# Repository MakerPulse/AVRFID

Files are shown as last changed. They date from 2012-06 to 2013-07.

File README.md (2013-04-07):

RPI-RFID
========

This project is ment to be used to scan and process RFID tags for attendance lists or access control.

Source - The code that is loaded onto the actual ID reader
Python_Interface - The GUI interface that is used to manage the attendance system
Circuit - The schematic and layout designes of the circuit board used to read the RFID tags
CaseCad - The CAD files for 3D printing the case for the circuit board

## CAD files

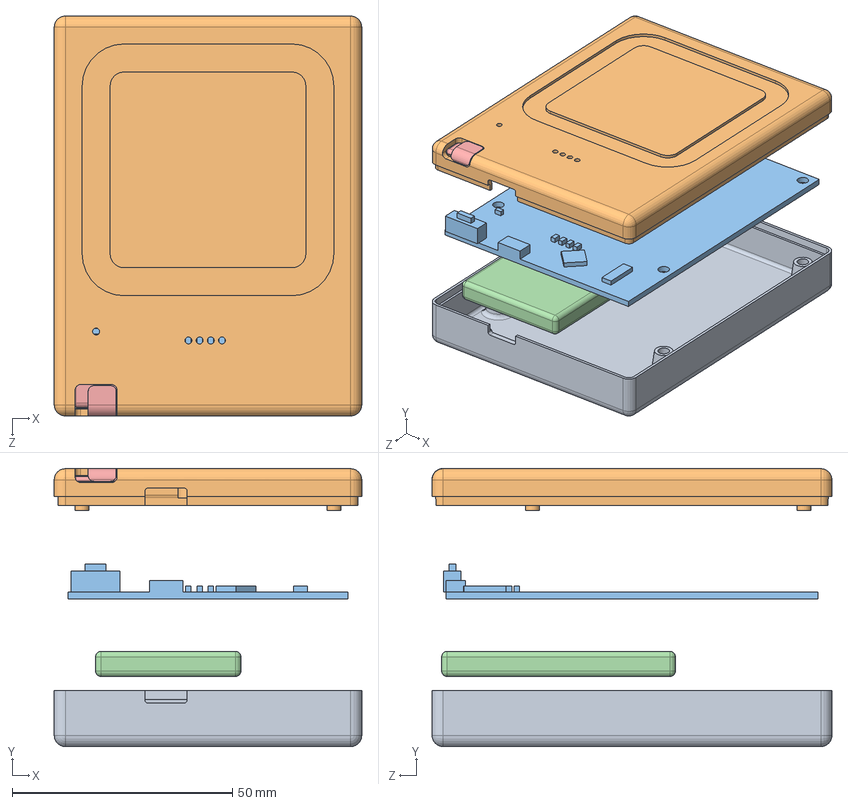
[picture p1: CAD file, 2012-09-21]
CaseCad/Assem1.SLDASM
69.8 x 63.2 x 90.8 mm
side1
side2
PCB
battery
switch

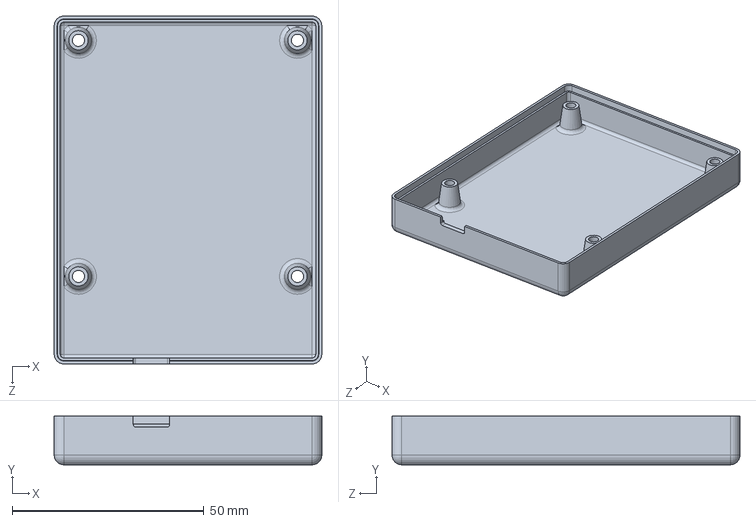
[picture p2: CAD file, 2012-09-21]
CaseCad/side1.SLDPRT
69.8 x 12.7 x 90.8 mm

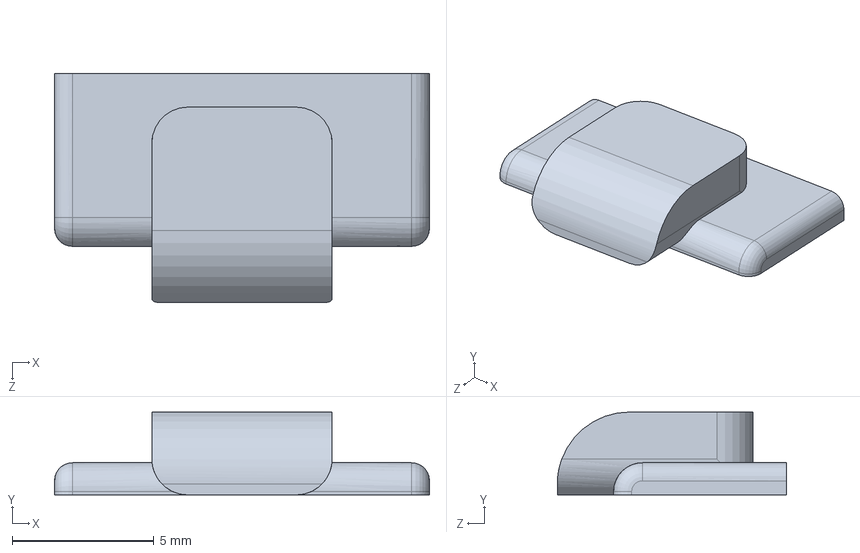
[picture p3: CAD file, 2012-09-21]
CaseCad/switch.SLDPRT
13.2 x 2.92 x 8.08 mm

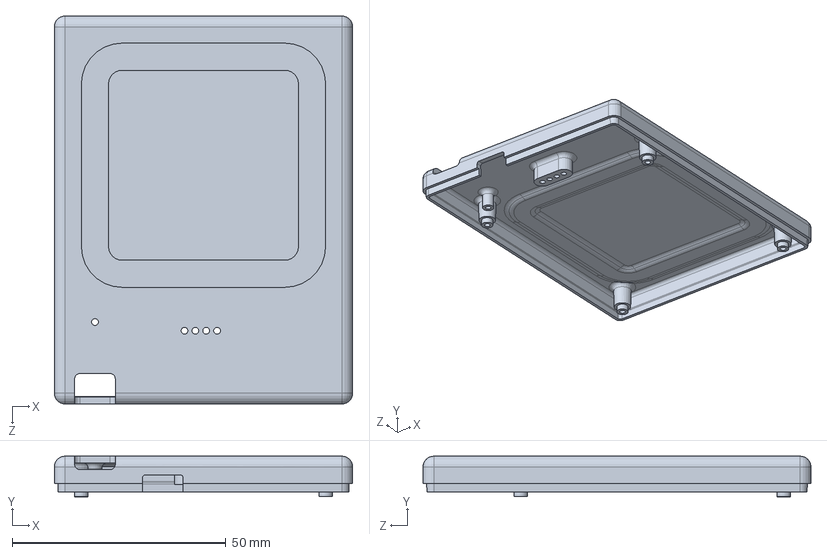
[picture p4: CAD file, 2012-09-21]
CaseCad/side2.SLDPRT
69.8 x 9.54 x 90.8 mm

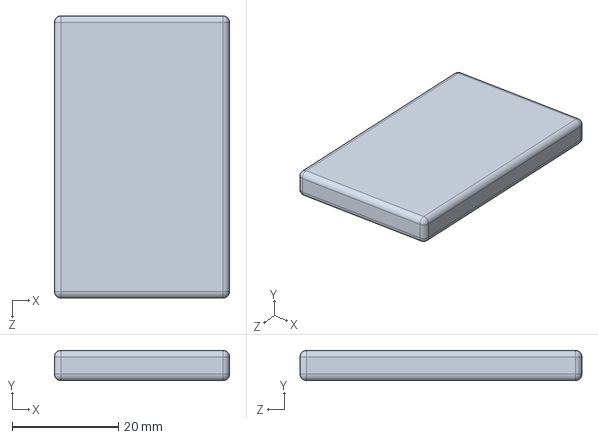
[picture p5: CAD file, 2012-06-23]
CaseCad/battery.SLDPRT
33.0 x 5.72 x 53.1 mm

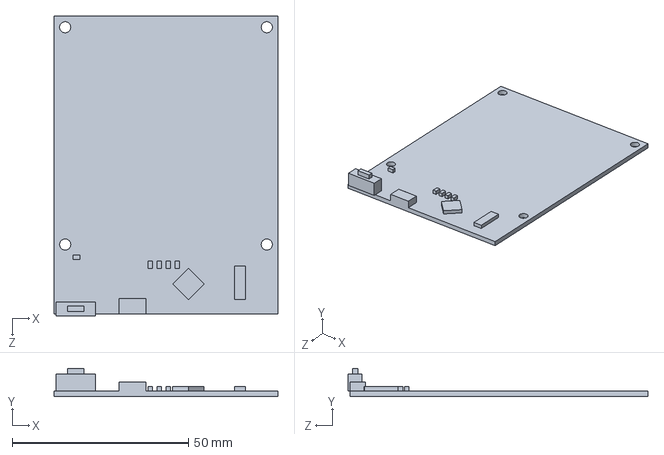
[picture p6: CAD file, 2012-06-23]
CaseCad/PCB.SLDPRT
63.5 x 7.95 x 85.0 mm

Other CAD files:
CaseCad/side1.STL
CaseCad/side2.STL
CaseCad/switch.STL

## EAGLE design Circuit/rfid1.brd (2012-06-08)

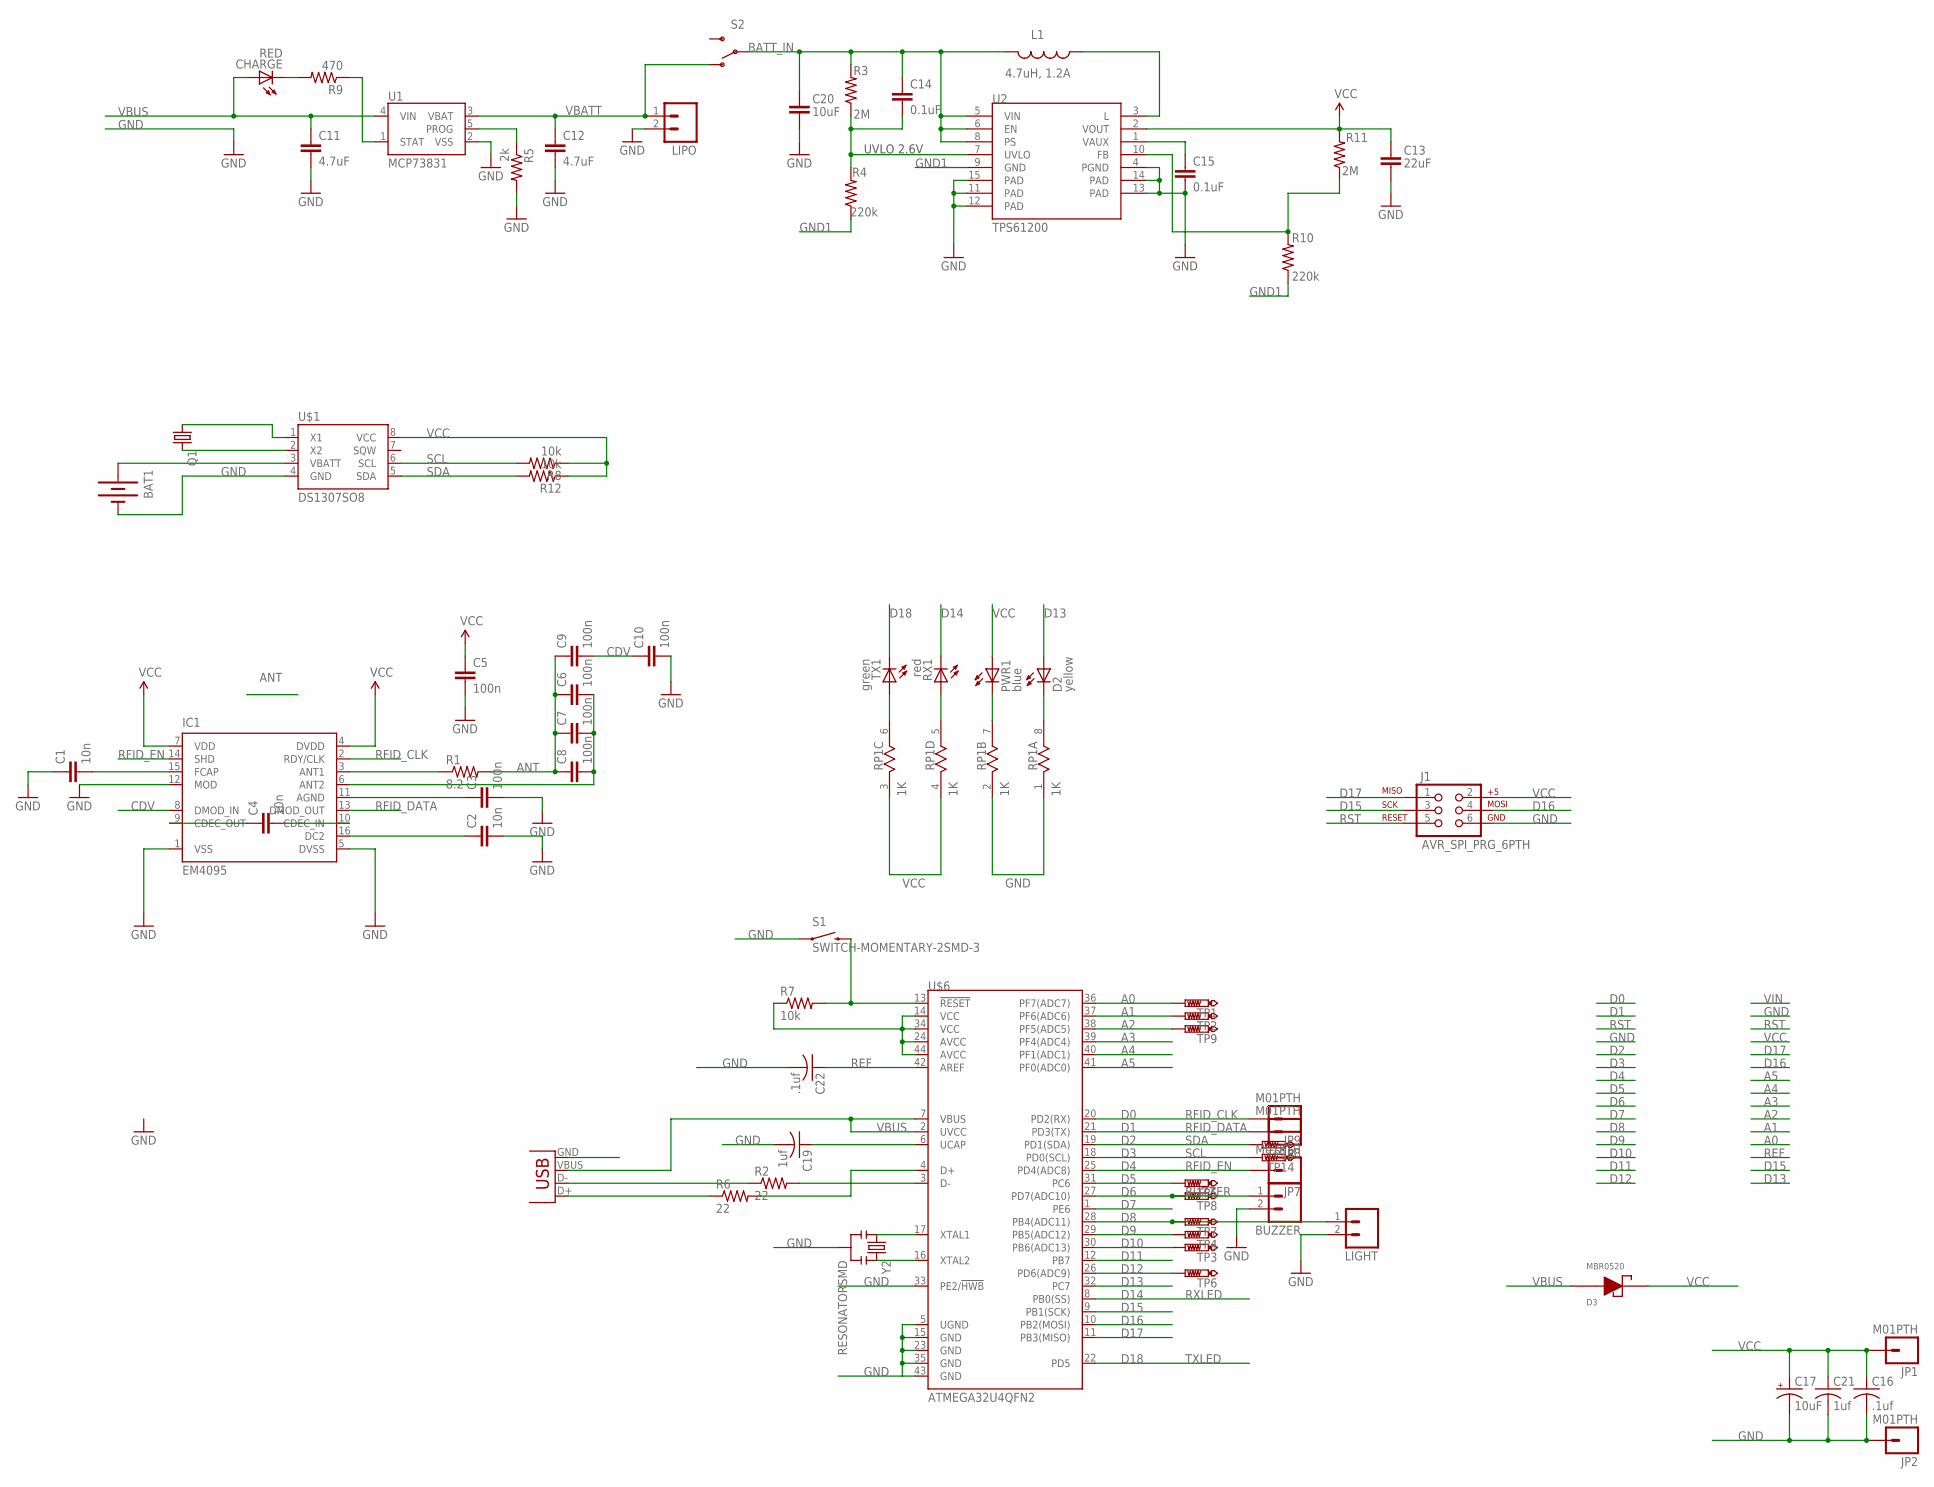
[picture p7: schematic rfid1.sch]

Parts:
BAT1: BATTERY12MM; BATTCON_12MM
BUZZER: M02PTH; 1X02
C1, C2, C4: 10n; 0805
C3, C5, C6, C7, C8, C9, C10: 100n; 0805
C11, C12: 4.7uF; 0603-CAP
C13: 22uF; 0805
C14, C15: 0.1uF; 0603-CAP
C16, C22: .1uf; C0603
C17: 10uF; EIA3216
C19, C21: 1uf; C0603
C20: 10uF; 1206
CHARGE: RED; CHIPLED_0805
D2: yellow; CHIPLED_0805
D3: MBR0520; SOD-123
IC1: EM4095; SO16
J1: AVR_SPI_PRG_6PTH; 2X3
JP1, JP2, JP7, JP8, JP9: M01PTH; 1X01
L1: 4.7uH, 1.2A; CDRH2D09
LIGHT: M02PTH; 1X02
LIPO: M02-JST-2-PTH-NO_SILK; JST-2-PTH-NS
PWR1: blue; CHIPLED_0805
Q1: CRYSTALTC26H; TC26H
R1: 8.2; 0805
R2, R6: 22; 0603-RES
R3, R11: 2M; 0603-RES
R4, R10: 220k; 0603-RES
R5: 2k; 0603-RES
R7, R8, R12: 10k; 0603-RES
R9: 470; 0603-RES
RP1: 1K; RES4NT
RX1: red; CHIPLED_0805
S1: SWITCH-MOMENTARY-2SMD-3; TACTILE_SWITCH_SMD-3
S2: SWITCH-SPDTPTH; SWITCH-SPDT
TP1, TP2, TP3, TP4, TP5, TP6, TP7, TP8, TP9, TP13, TP14: PTR1TP14R; TP14R
TX1: green; CHIPLED_0805
U1: MCP73831; SOT23-5
U2: TPS61200; QFN-10_PAD
U$1: DS1307SO8; SO08
U$6: ATMEGA32U4QFN2; QFN-44-NOPAD
X2: USB-MICROB
Y2: RESONATORSMD; RESONATOR-SMD

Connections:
A0: TP1.TP, U$6.36 (PF7(ADC7))
A1: TP2.TP, U$6.37 (PF6(ADC6))
A2: TP9.TP, U$6.38 (PF5(ADC5))
A3: U$6.39 (PF4(ADC4))
A4: U$6.40 (PF1(ADC1))
A5: U$6.41 (PF0(ADC0))
ANT: C6.1, C7.1, C8.1, C9.1, R1.2
BATT_IN: C14.1, C20.1, L1.P$2 (2), R3.2, S2.2, U2.5 (VIN), U2.6 (EN), U2.8 (PS)
CDV: C9.2, C10.1, IC1.8 (DMOD_IN)
D5: TP5.TP, U$6.31 (PC6)
D6: BUZZER.1, TP8.TP, U$6.27 (PD7(ADC10))
D7: U$6.1 (PE6)
D8: LIGHT.1, TP7.TP, U$6.28 (PB4(ADC11))
D9: TP4.TP, U$6.29 (PB5(ADC12))
D10: TP3.TP, U$6.30 (PB6(ADC13))
D11: U$6.12 (PB7)
D12: TP6.TP, U$6.26 (PD6(ADC9))
D13: D2.A, U$6.32 (PC7)
D14: RX1.C, U$6.8 (PB0(SS))
D15: J1.3, U$6.9 (PB1(SCK))
D16: J1.4, U$6.10 (PB2(MOSI))
D17: J1.1, U$6.11 (PB3(MISO))
D18: TX1.C, U$6.22 (PD5)
FB: R10.2, R11.1, U2.10 (FB)
GND: BAT1.GND (-), BUZZER.2, C1.1, C2.2, C3.2, C5.2, C10.2, C11.2, C12.2, C13.2, C15.2, C16.2, C17.C (-), C19.2, C20.2, C21.2, C22.2, IC1.1 (VSS), IC1.5 (DVSS), IC1.12 (MOD), J1.6, JP2.1, LIGHT.2, LIPO.2, R5.2, RP1.1, RP1.2 (1), S1.P$1 (1), U1.2 (VSS), U2.4 (PGND), U2.11 (PAD), U2.12 (PAD), U2.13 (PAD), U2.14 (PAD), U2.15 (PAD), U$1.4 (GND), U$6.5 (UGND), U$6.15 (GND), U$6.23 (GND), U$6.33 (PE2/!HWB), U$6.35 (GND), U$6.43 (GND), X2.GND, Y2.2
GND1: R4.1, R10.1, U2.9 (GND)
unnamed: IC1.3 (ANT1), R1.1
unnamed: CHARGE.C, R9.2
unnamed: U$6.16 (XTAL2), Y2.3
unnamed: C6.2, C7.2, C8.2, IC1.6 (ANT2)
unnamed: L1.P$1 (1), U2.3 (L)
unnamed: C3.1, IC1.11 (AGND)
unnamed: C4.2, IC1.10 (CDEC_IN)
unnamed: C4.1, IC1.9 (CDEC_OUT)
unnamed: C15.1, U2.1 (VAUX)
unnamed: R5.1, U1.5 (PROG)
unnamed: C2.1, IC1.16 (DC2)
unnamed: R9.1, U1.1 (STAT)
unnamed: C1.2, IC1.15 (FCAP)
unnamed: Q1.1, U$1.1 (X1)
unnamed: U$6.17 (XTAL1), Y2.1
unnamed: Q1.2, U$1.2 (X2)
unnamed: BAT1.PWR@1 (+), U$1.3 (VBATT)
unnamed: R6.2, U$6.4 (D+)
unnamed: R2.2, U$6.3 (D-)
unnamed: C19.1, U$6.6 (UCAP)
unnamed: R2.1, X2.D-
unnamed: R6.1, X2.D+
unnamed: RP1.6 (2), TX1.A
unnamed: RP1.5 (2), RX1.A
unnamed: PWR1.C, RP1.7 (2)
unnamed: D2.C, RP1.8 (2)
REF: C22.1, U$6.42 (AREF)
RFID_CLK: IC1.2 (RDY/CLK), JP9.1, U$6.20 (PD2(RX))
RFID_DATA: IC1.13 (DMOD_OUT), JP8.1, U$6.21 (PD3(TX))
RFID_EN: IC1.14 (SHD), JP7.1, U$6.25 (PD4(ADC8))
RST: J1.5, R7.2, S1.P$2 (2), U$6.13 (!RESET)
SCL: R8.2, TP14.TP, U$1.6 (SCL), U$6.18 (PD0(SCL))
SDA: R12.2, TP13.TP, U$1.5 (SDA), U$6.19 (PD1(SDA))
UVLO: C14.2, R3.1, R4.2, U2.7 (UVLO)
VBATT: C12.1, LIPO.1, S2.1 (O), U1.3 (VBAT)
VBUS: C11.1, CHARGE.A, D3.2 (AN), U1.4 (VIN), U$6.2 (UVCC), U$6.7 (VBUS), X2.VBUS
VCC: C5.1, C13.1, C16.1, C17.A (+), C21.1, D3.1 (CA), IC1.4 (DVDD), IC1.7 (VDD), J1.2, JP1.1, PWR1.A, R7.1, R8.1, R11.2, R12.1, RP1.3 (1), RP1.4 (1), U2.2 (VOUT), U$1.8 (VCC), U$6.14 (VCC), U$6.24 (AVCC), U$6.34 (VCC), U$6.44 (AVCC)

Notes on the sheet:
RXLED
TXLED
UVLO 2.6V
BUZZER

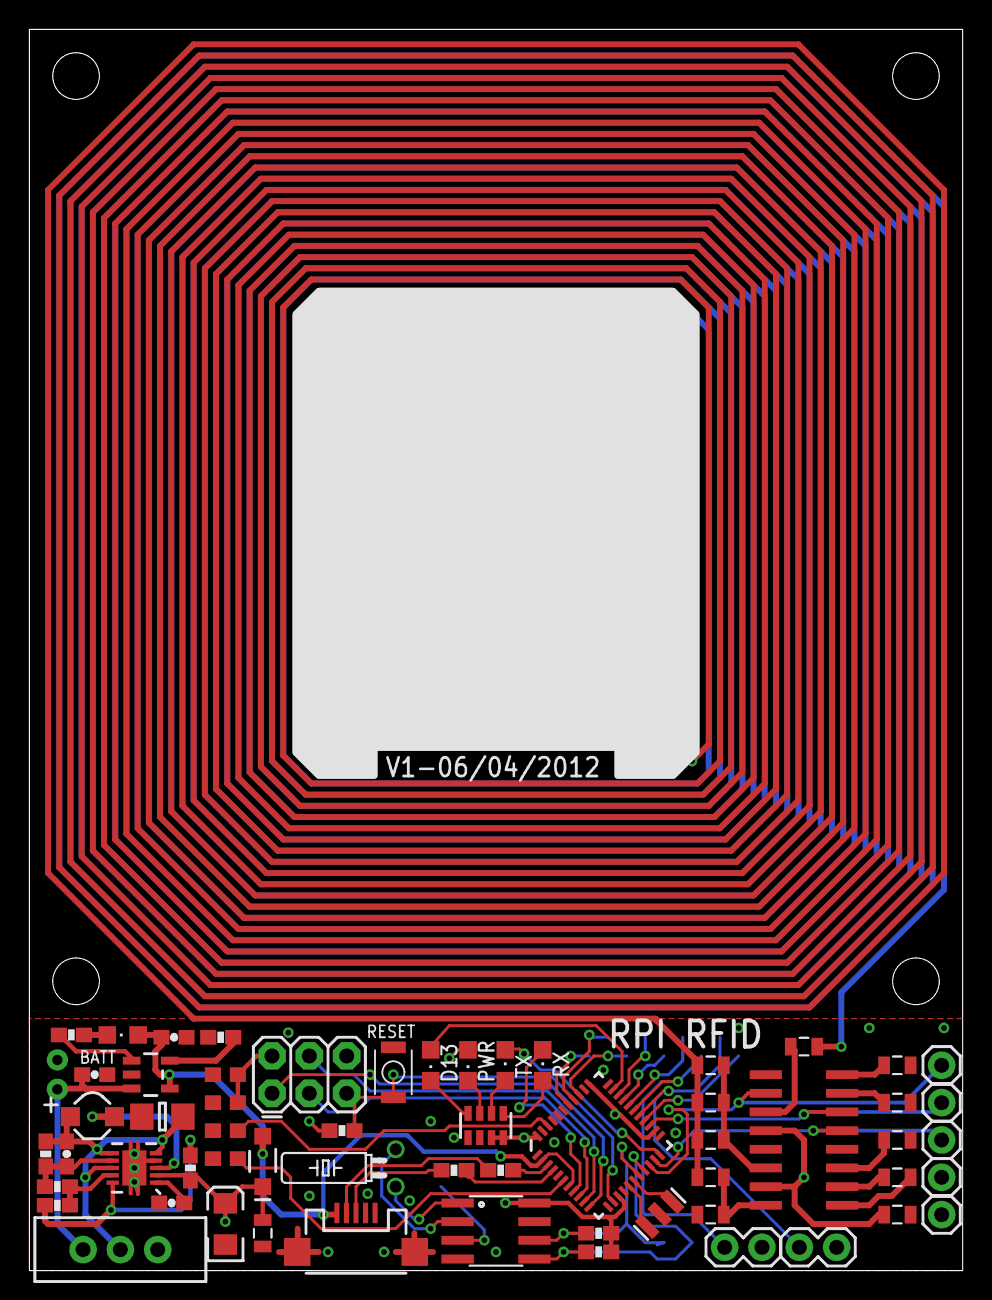
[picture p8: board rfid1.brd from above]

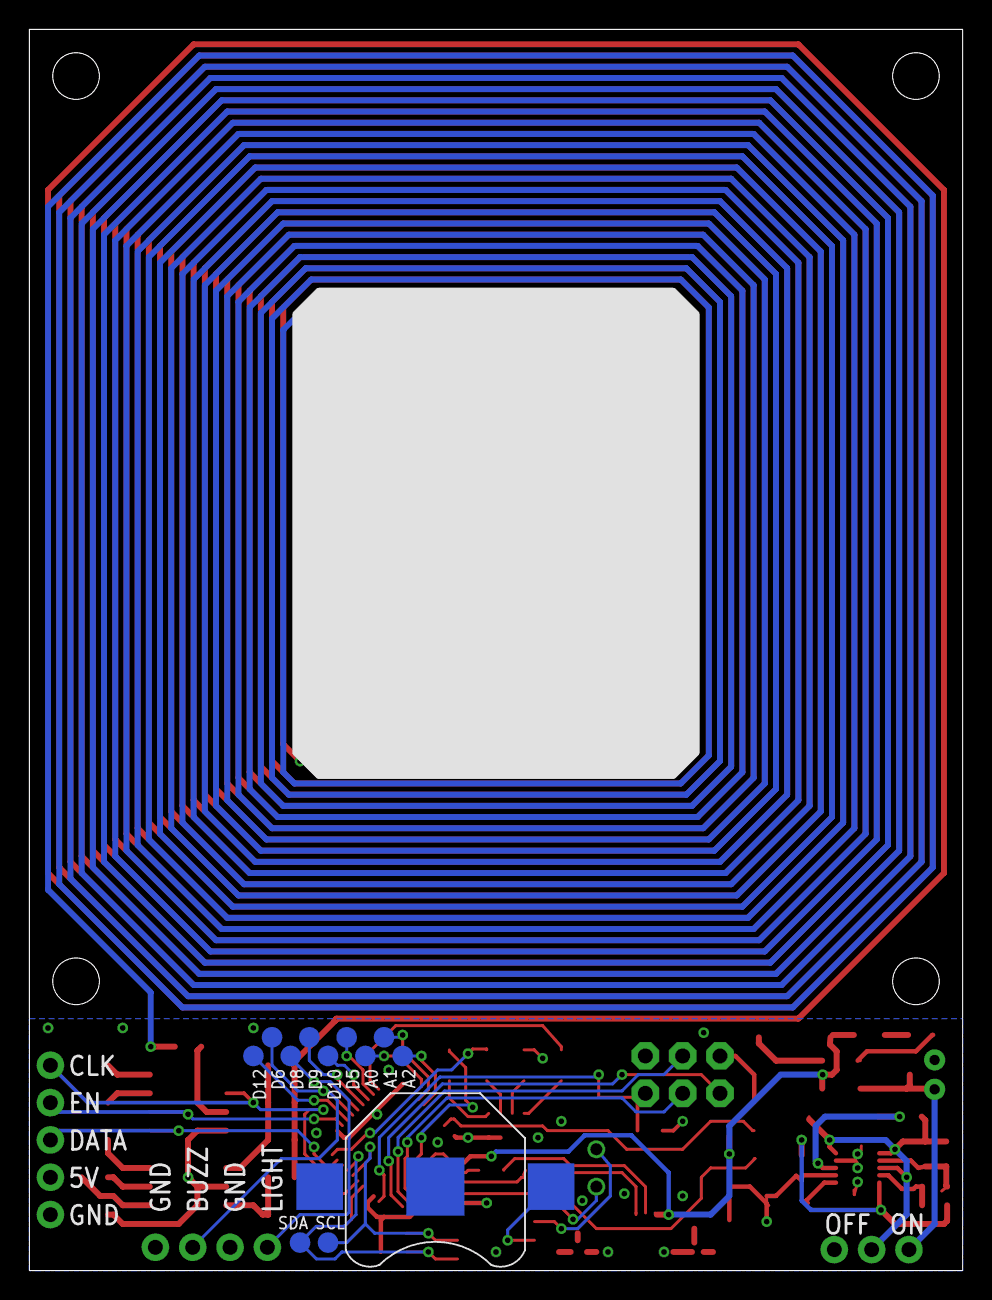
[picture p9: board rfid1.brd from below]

Board: 2 copper layers, 63.5 x 84.5 mm, 72 parts (13 on the bottom side), 58 nets.

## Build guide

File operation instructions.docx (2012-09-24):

Using RPI RFID Read software

Open the application RFID_Serial_Interface3.exe. Note the date displayed in the upper left corner. This is the name that will be assigned to the output file. The numbers in the lower left corner represent the mouse coordinates. These can be ignored.

click load, and navigate to RFID list file. This is a .csv (comma separated value) file containing a list of names, RCS IDs, RFID tags, and roles. The roles category is user configurable, and for reference only. It has no effect on the operation of the program, so long as it doesn’t exceed 30 characters. The header is defined in the CSV file.

Click open. The program will load the names into the list. Note the open file name in the upper right corner.

In order to begin scanning IDs, we need to open the serial port the RFID reader is connected to. Use device manager to identify the correct COM Port. I know that COM 10 is the RFID reader on my system, but it will be different from system to system. Usually it is a lower number.

Click the ‘serial’ button to detect and select the serial port. It will take a few seconds to load. Enter the number preceding the correct port. This example is 2. Press enter.

The port will open and the program will display ‘OK to scan’ indicating that it is ready to scan IDs and log entries. It will also show the open port next to the file name. The system is ready to scan IDs now.

Scanning an ID causes the list to jump to the correct ID location in the list, and mark that person as ‘present’.

If an ID is scanned that is not in the list, it will prompt the user to enter the rest of the information, then add the new entry to the list and mark as present.

Clicking edit allows the user to change the information of the current entry. The information must be entered in the format specified, and include the name, email, and user field with no spaces between commas. Sorry. It also allows the user to scan a new or replacement ID.

Clicking ‘add’ allows the user to add a new entry by name. The field must be entered as described, without spaces between the commas. Sorry. It assigns an ID of ‘00000000000’ and marks them as present. This is generally only used for RPI Faculty, staff, or students who forget their ID, or for attendees without an RPI ID.

Attendees can be marked as present manually using the ‘mark’ button. This toggles the ‘present’ state.

A user can search the list for a matching string in any of the Name, email, or role fields. The text is case sensitive and must match exactly, including spaces. First or Last name only are not enough, it must be the exact entered name. Short or nicknames in the list may cause problems here. Entering the email correctly is the best option for reliable searches each time. Scanning an ID will cause the list to jump to a correct entry if available.

If an attendee is known to be on the list, but their ID says they are unknown, they may have gotten a new ID. Click ‘search’ to search for their email before adding a new entry. If that turns up nothing, create a new entry.

Closing the application will save both the list of names, emails, RFID tags, and roles, and the list of those present for the event. If another event is needed for the day, the file name must be manually changed on the first before saving the second, or it will be overwritten. The list file location is the same as it was selected. The event file location is in the same folder from which the application was run.

Known Issues

- Event files are overwritten, and cannot be appended to. This means one event per day without closing the application between reads, or without manually changing the file name
- Event file location is not configurable within the application. It can be changed in source though.

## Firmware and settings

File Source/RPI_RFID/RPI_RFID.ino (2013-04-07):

/******************************* CUSTOM SETTINGS ******************************\
| Settings that can be changed, comment or uncomment these #define settings to |
| make the AVRFID code do different things
\******************************************************************************/

//#define Binary_Tag_Output         // Outputs the Read tag in binary over serial
#define Hexadecimal_Tag_Output    // Outputs the read tag in Hexadecimal over serial
//#define Decimal_Tag_Output        // Outputs the read tag in decimal

#define Manufacturer_ID_Output    // The output will contain the Manufacturer ID (NOT IMPLEMENTED)
#define Site_Code_Output          // The output will contain the Site Code       (NOT IMPLEMENTED)
#define Unique_Id_Output          // The output will contain the Unique ID

//#define Split_Tags_With '-'       // The character to split tags pieces with


//20-bit manufacturer code,
#define MANUFACTURER_ID_OFFSET 0
#define MANUFACTURER_ID_LENGTH 20

//8-bit site code
#define SITE_CODE_OFFSET 20
#define SITE_CODE_LENGTH 8

//16-bit unique id
#define UNIQUE_ID_OFFSET 28
#define UNIQUE_ID_LENGTH 16



// these settings are used internally by the program to optimize the settings above
#ifndef serialOut
  #define serialOut
#endif


/// countBuffer the includes

//#include <avr/io.h>
//#include <avr/interrupt.h>
//#include <stdlib.h>

#define ARRAYSIZE 900   // Number of RF points to collect each time
#define bufferType char

bufferType * countBuffer;           // points to the bigining of the array
int * names;            // array of valid ID numbers
int namesize;           // size of array of valid ID numbers
volatile int iter;      // the iterator for the placement of count in the array
volatile int count;     // counts 125kHz pulses
volatile int lastpulse; // last value of DEMOD_OUT
volatile int on;        // stores the value of DEMOD_OUT in the interrupt


/******************************* MAIN FUNCTION *******************************\
| This is the main function, it initilized the variabls and then waits for    |
| interrupt to fill the buffer before analizing the gathered data             |
\*****************************************************************************/
void setup () {
  
  ///////////// PIN INITILIZATION /////////////
  //DDRD = 0x00; // 00000000 configure output on port D
  //DDRB = 0x1E; // 00011100 configure output on port B
  
  // USART INITILIZATION
  Serial.begin(9600);
  Serial.println("Finished setup");
  //Serial.end();
  //Serial1.countBuffer(9600);
  //Serial1.println("Serial  1");
  //Serial2.countBuffer(9600);
  //Serial2.println("Serial 2");
  
  /////////// VARIABLE INITILIZATION //////////
  count = 0;
  countBuffer = (bufferType *) malloc (sizeof(bufferType)*ARRAYSIZE);
  iter = 0;
  for (int i = 0; i < ARRAYSIZE; i ++) {
    countBuffer[i] = 0;
  }
  
  ////////// INTERRUPT INITILAIZATION /////////
  //sei ();       // enable global interrupts
  //cli ();// disable global interrupts
  //__enable_interrupt();
  EIMSK = 0x00;
  EICRA = 0x30; // configure interupt INT2 B 0011 0000
  //enableAntenna();
  //__disable_interrupt();
  sei();
  Serial.println("Finished setup");
  pinMode(4,OUTPUT);
  digitalWrite(4,LOW);
  //pinMode(1,INPUT);
  //DDRD &= 0xFC;
  DDRD &= ~0x04;
  DDRD &= ~0x02;
  //PORTD |= 0x06;
  
  DDRD |= 0x80;
  PORTD |= 0x80;
  
  pinMode(13,OUTPUT);
  digitalWrite(13,HIGH);
}

void loop () {
  Serial.end();
  enableAntenna();
  //__enable_interrupt();  
  while (1) { // while the card is being read
    /*Serial.print(on);
    Serial.print(" ");
    Serial.println(count);*/
    if (iter >= ARRAYSIZE) { // if the buffer is full
      disableAntenna();
      //__disable_interrupt();
      //noInterrupts();
      break; // continue to analize the buffer
    }
  }  
  //Serial.println("Finished array");
  //PORTB &= ~0x1C;
  Serial.begin(9600);
  //analize the array of input
  analizeInput ();
  
  //reset the saved values to prevent errors when reading another card
  count = 0;
  iter = 0;
  for (int i = 0; i < ARRAYSIZE; i ++) {
    countBuffer[i] = 0;
  }
}

/******************************* INT0 INTERRUPT *******************************\
| This ISR(INT0_vect) is the interrupt function for INT0. This function is the |
| function that is run each time the 125kHz pulse goes HIGH.                   |
| 1) If this pulse is in a new wave then put the count of the last wave into   |
|     the array                                                                |
| 2) Add one to the count (count stores the number of 125kHz pulses in each    |
|     wave                                                                     |
\******************************************************************************/
ISR(INT2_vect) {
  //Save the value of DEMOD_OUT to prevent re-reading on the same group
  on =(PIND & 0x08);
  
  //if (on==0x08) PORTD |= 0x80;
  //else { PORTD &= ~0x80; }
  
  //on = digitalRead(1);
  // if wave is rising (end of the last wave)
  if (on == 0x08 && lastpulse == 0 ) {
    //PORTD |= 0x80;
    // write the data to the array and reset the count
    countBuffer[iter] = count; 
    count = 0;
    iter = iter + 1;
  }
  count = count + 1;
  lastpulse = on;
}


void disableAntenna(){
  EIMSK = 0x00; // disable interrupt INT2    B 0000 0000
}
void enableAntenna() {
  EIMSK = 0x04; // enable interrupt INT2    B 0000 0100
}

  //////////////////////////////////////////////////////////////////////////////
 ////////////////////////// BASE CONVERSION FUNCTIONS /////////////////////////
//////////////////////////////////////////////////////////////////////////////
char binaryTohex (int four, int three, int two, int one) {
  int value = (one << 0) + (two << 1) + (three << 2) + (four << 3);
  if (value > 9) return 'A' + value - 10;
  return '0' + value;
}

/*********************** GET HEX ARRAY FROM BINARY ARRAY **********************\
|
\******************************************************************************/
int * getHexFromBinary (int * array, int length, int * result) {
  int i;
  int resultLength = (length+3)/4; // +3 so that the resulting number gets rounded up
  // 4 / 4 = 1       [correct]
  // 7 / 4 = 1 (4+3) [still correct]
  // 5 / 4 = 1       [not rounded up]
  // 8 / 4 = 2 (5+3) [correct]
  
  for (i = 0; i < resultLength; i++) {
    result[i*4] = (array[i+0] << 0)
                + (array[i+1] << 1)
                + (array[i+2] << 2)
                + (array[i+3] << 3);
  }
  return result;
}
/*************************** GET DECIMAL FROM BINARY **************************\
| This function will take in a binary input and return an intiger with the     |
| corrisponding value, assumed as decimal                                      |
\******************************************************************************/
int getDecimalFromBinary (int * array, int length) {  
  int result = 0;
  int i;
  for (i = 0; i < length; i++) {
    result = result<<1;
    result += array[i]&0x01;
  }
  return result;
}


void recurseDecimal (unsigned int val) {
  if (val > 0 ) {
    recurseDecimal(val/10);
    Serial.print(val%10);
  }
  return;
}

void printDecimal (int array[45]) {
  #ifdef Manufacturer_ID_Output
  int manufacturerId = getDecimalFromBinary( array + MANUFACTURER_ID_OFFSET,MANUFACTURER_ID_LENGTH);
  manufacturerId = getDecimalFromBinary( array + MANUFACTURER_ID_OFFSET,MANUFACTURER_ID_LENGTH);
  recurseDecimal(manufacturerId);
  #endif
  
  #ifdef Split_Tags_With
    Serial.print(Split_Tags_With);
  #endif
  
  #ifdef Site_Code_Output
  
  int siteCode = getDecimalFromBinary( array + SITE_CODE_OFFSET,SITE_CODE_LENGTH);
  recurseDecimal(siteCode);
  #endif

  #ifdef Split_Tags_With
    Serial.print(Split_Tags_With);
  #endif

  #ifdef Unique_Id_Output
  int lastId = getDecimalFromBinary( array + UNIQUE_ID_OFFSET,UNIQUE_ID_LENGTH);
  recurseDecimal(lastId);
  #endif
  
  Serial.print('\r');
  Serial.print('\n');
}
void printHexadecimal (int array[45]) {
  int i;
  #ifdef Manufacturer_ID_Output
  for (i = MANUFACTURER_ID_OFFSET; i < MANUFACTURER_ID_OFFSET+MANUFACTURER_ID_LENGTH; i+=4) {
    Serial.print(binaryTohex(array[i],array[i+1],array[i+2],array[i+3]));
  }
  #endif
  
  #ifdef Split_Tags_With
    Serial.print(Split_Tags_With);
  #endif
  
  #ifdef Site_Code_Output
  for (i = SITE_CODE_OFFSET; i < SITE_CODE_OFFSET+SITE_CODE_LENGTH; i+=4) {
    Serial.print(binaryTohex(array[i],array[i+1],array[i+2],array[i+3]));
  }
  #endif

  #ifdef Split_Tags_With
    Serial.print(Split_Tags_With);
  #endif

  #ifdef Unique_Id_Output
  for (i = UNIQUE_ID_OFFSET; i < UNIQUE_ID_OFFSET+UNIQUE_ID_LENGTH; i+=4) {
    Serial.print(binaryTohex(array[i],array[i+1],array[i+2],array[i+3]));
  }
  #endif
  Serial.print('\r');
  Serial.print('\n');
}



void printBinary (int array[45]) {
  int i;
  #ifdef Manufacturer_ID_Output
  for (i = MANUFACTURER_ID_OFFSET; i < MANUFACTURER_ID_OFFSET+MANUFACTURER_ID_LENGTH; i++) {
    Serial.print(array[i]);
  }
  #endif
  
  #ifdef Split_Tags_With
    Serial.print(Split_Tags_With);
  #endif
  
  #ifdef Site_Code_Output
  for (i = SITE_CODE_OFFSET; i < SITE_CODE_OFFSET+SITE_CODE_LENGTH; i++) {
    Serial.print(array[i]);
  }
  #endif

  #ifdef Split_Tags_With
    Serial.print(Split_Tags_With);
  #endif

  #ifdef Unique_Id_Output
  for (i = UNIQUE_ID_OFFSET; i < UNIQUE_ID_OFFSET+UNIQUE_ID_LENGTH; i++) {
    Serial.print(array[i]);
  }
  #endif
  Serial.print('\r');
  Serial.print('\n');
}



  //////////////////////////////////////////////////////////////////////////////
 ///////////////////////////// ANALYSIS FUNCTIONS /////////////////////////////
//////////////////////////////////////////////////////////////////////////////

/************************* CONVERT RAW DATA TO BINARY *************************\
| Converts the raw 'pulse per wave' count (5,6,or 7) to binary data (0, or 1)  |
\******************************************************************************/
void convertRawDataToBinary (bufferType * buffer) {
  int i;
  int outputOffset = 0;
  //Serial.print("FULL BUFFER");
  buffer[0] = -2;
  for (i = 1; i < ARRAYSIZE; i++) {
    /*
    if (buffer[i] == 5) {
      buffer[i] = 0;
    }
    else if (buffer[i] == 7) {
      buffer[i] = 1;
    }
    else if (buffer[i] == 6) {
       buffer[i] = buffer[i-1];
    }*/
    //Serial.print(int(buffer[i]));
    //Serial.print('|');
    
    if (buffer[i] <= 8 && buffer[i] >= 6) {
      buffer[i-outputOffset] = 0;
    }
    else if (buffer[i] >= 10 && buffer[i] <= 18) {
      buffer[i-outputOffset] = 1;
    }
    else if (buffer[i] == 9) {
      buffer[i-outputOffset] = buffer[i-outputOffset-1];
    }
    else {
      outputOffset++;//increase the offset so that this element gets overwritten by the next element instead
      buffer[ARRAYSIZE-outputOffset] = -2; // Set the end of the array to a -2 to prevent previous data from carrying over
    }
    
    //Serial.print(int(buffer[i-outputOffset]));
  }
  //Serial.println("");
}
/******************************* FIND START TAG *******************************\
| This function goes through the buffer and tries to find a group of fifteen   |
| or more 1's in a row. This sigifies the start tag. If you took the fifteen   |
| ones in multibit they would come out to be '111' in single-bit               |
\******************************************************************************/
int findStartTag (bufferType * buffer) {
  int i;
  int inARow = 0;
  int lastVal = 0;
  for (i = 0; i < ARRAYSIZE; i++) {
    if (buffer [i] == lastVal) {
      inARow++;
    }
    else {
      // End of the group of bits with the same value
      if (inARow >= 15 && lastVal == 1) {
        // Start tag found
        break;
      }
      // group of bits was not a start tag, search next tag
      inARow = 1;
      lastVal = buffer[i];
    }
  }
  return i;
}

/************************ PARSE MULTIBIT TO SINGLE BIT ************************\
| This function takes in the start tag and starts parsing the multi-bit code   |
| to produce the single bit result in the outputBuffer array the resulting     |
| code is single bit manchester code                                           |
\******************************************************************************/
void parseMultiBitToSingleBit (bufferType * buffer, int startOffset, int outputBuffer[]) {
  int i = startOffset; // the offset value of the start tag
  int lastVal = 0; // what was the value of the last bit
  int inARow = 0; // how many identical bits are in a row// this may need to be 1 but seems to work fine
  int resultArray_index = 0;
  for (;i < ARRAYSIZE; i++) {
    if (buffer [i] == lastVal) {
      inARow++;
    }
    else {
      // End of the group of bits with the same value
      if (inARow >= 4 && inARow <= 8) {
        // there are between 4 and 8 bits of the same value in a row
        // Add one bit to the resulting array
        outputBuffer[resultArray_index] = lastVal;
        resultArray_index += 1;
      }
      else if (inARow >= 9 && inARow <= 14) {
        // there are between 9 and 14 bits of the same value in a row
        // Add two bits to the resulting array
        outputBuffer[resultArray_index] = lastVal;
        outputBuffer[resultArray_index+1] = lastVal;
        resultArray_index += 2;
      }
      else if (inARow >= 15 && lastVal == 0) {
        // there are more then 15 identical bits in a row, and they are 0s
        // this is an end tag
        break;
      }
      // group of bits was not the end tag, continue parsing data
      inARow = 1;
      lastVal = buffer[i];
      if (resultArray_index >= 90) {
        //Serial.println("Out of bounds error");
        return;
      }
    }
  }
}

/******************************* Analize Input *******************************\
| analizeInput(void) parses through the global variable and gets the 45 bit   |
| id tag.                                                                     |
| 1) Converts raw pulse per wave count (5,6,7) to binary data (0,1)           |
| 2) Finds a start tag in the code                                            |
| 3) Parses the data from multibit code (11111000000000000111111111100000) to |
|     singlebit manchester code (100110) untill it finds an end tag           |
| 4) Converts manchester code (100110) to binary code (010)                   |
\*****************************************************************************/
void analizeInput (void) {
  //Serial.println ("READ ");
  
  int i;                // Generic for loop 'i' counter
  int resultArray[91];  // Parsed Bit code in manchester
  int finalArray[45];   //Parsed Bit Code out of manchester
  int finalArray_index = 0;
  
  // Initilize the arrays so that any errors or unchanged values show up as 2s
  for (i = 0; i < 90; i ++) { resultArray[i] = 2; }
  for (i = 0; i < 45; i++)  { finalArray[i] = 2;  }
  
  // Convert raw data to binary
  convertRawDataToBinary (countBuffer);
  
  
  
  
  
  // Find Start Tag
  int startOffset = findStartTag(countBuffer);
  //PORTB |= 0x10; // turn an led on on pin B5)
  
  // Parse multibit data to single bit data
  parseMultiBitToSingleBit(countBuffer, startOffset, resultArray);
  
    
  //return;
    
  /*
  Serial.print("SINGLE BIT BUFFER: ");
  for (i = 0; i < 88; i++) { // ignore the parody bit ([88] and [89])
    Serial.print(resultArray[i]);
  }
  Serial.println("");
  */
  
  // Error checking, see if there are any unset elements of the array
  for (i = 0; i < 88; i++) { // ignore the parody bit ([88] and [89])
    if (resultArray[i] == 2) {
      //Serial.println("BAD-UNSET ELEMENT");
      return;
    }
  }
  
  //Serial.print("Manchester: ");
  //------------------------------------------
  // MANCHESTER DECODING
  //------------------------------------------
  for (i = 0; i < 88; i+=2) { // ignore the parody bit ([88][89])
    if (resultArray[i] == 1 && resultArray[i+1] == 0) {
      finalArray[finalArray_index] = 1;
    }
    else if (resultArray[i] == 0 && resultArray[i+1] == 1) {
      finalArray[finalArray_index] = 0;
    }
    else {
      // The read code is not in manchester, ignore this read tag and try again
      // free the allocated memory and end the function
      //Serial.println("BAD-NONMANCHESTER");
      //for (int j = 0; j < 88; j++) {
      //  Serial.print(resultArray[j]);
      //}
      //Serial.println("");
      return;
    }
    finalArray_index++;
  }
  
  /*
  for (i = 0; i<44; i++) {
    Serial.print(finalArray[i]);
  }
  Serial.println("END");
  */
  
  
    
  
  #ifdef Binary_Tag_Output         // Outputs the Read tag in binary over serial
    printBinary (finalArray);
  #endif
    
  #ifdef Hexadecimal_Tag_Output    // Outputs the read tag in Hexadecimal over serial
    printHexadecimal (finalArray);
  #endif
    
  #ifdef Decimal_Tag_Output
    printDecimal (finalArray);
  #endif
  
  digitalWrite(13,HIGH);
  delay(500);
  digitalWrite(13,LOW);
}

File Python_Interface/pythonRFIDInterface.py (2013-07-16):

#!/usr/bin/env python2
################################### SIGNATURE ##################################
#                                      ,,                                      #
#                     db             `7MM                                      #
#                    ;MM:              MM                                      #
#                   ,V^MM.    ,pP"Ybd  MMpMMMb.  .gP"Ya `7Mb,od8               #
#                  ,M  `MM    8I   `"  MM    MM ,M'   Yb  MM' "'               #
#                  AbmmmqMA   `YMMMa.  MM    MM 8M""""""  MM                   #
#                 A'     VML  L.   I8  MM    MM YM.    ,  MM                   #
#               .AMA.   .AMMA.M9mmmP'.JMML  JMML.`Mbmmd'.JMML.                 #
#                                                                              #
#                                                                              #
#                                  ,,    ,,                                    #
#                      .g8"""bgd `7MM    db        `7MM                        #
#                    .dP'     `M   MM                MM                        #
#                    dM'       `   MM  `7MM  ,p6"bo  MM  ,MP'                  #
#                    MM            MM    MM 6M'  OO  MM ;Y                     #
#                    MM.    `7MMF' MM    MM 8M       MM;Mm                     #
#                    `Mb.     MM   MM    MM YM.    , MM `Mb.                   #
#                      `"bmmmdPY .JMML..JMML.YMbmd'.JMML. YA.                  #
#                                                                              #
################################################################################
#################################### LICENSE ###################################
# Copyright (c) 2012, Asher Glick                                              #
# All rights reserved.                                                         #
#                                                                              #
# Redistribution and use in source and binary forms, with or without           #
# modification, are permitted provided that the following conditions are met:  #
#                                                                              #
# * Redistributions of source code must retain the above copyright notice,     #
# this                                                                         #
#   list of conditions and the following disclaimer.                           #
# * Redistributions in binary form must reproduce the above copyright notice,  #
#   this list of conditions and the following disclaimer in the documentation  #
#   and/or other materials provided with the distribution.                     #
#                                                                              #
# THIS SOFTWARE IS PROVIDED BY THE COPYRIGHT HOLDERS AND CONTRIBUTORS "AS IS"  #
# AND ANY EXPRESS OR IMPLIED WARRANTIES, INCLUDING, BUT NOT LIMITED TO, THE    #
# IMPLIED WARRANTIES OF MERCHANTABILITY AND FITNESS FOR A PARTICULAR PURPOSE   #
# ARE DISCLAIMED. IN NO EVENT SHALL THE COPYRIGHT HOLDER OR CONTRIBUTORS BE    #
# LIABLE FOR ANY DIRECT, INDIRECT, INCIDENTAL, SPECIAL, EXEMPLARY, OR          #
# CONSEQUENTIAL DAMAGES (INCLUDING, BUT NOT LIMITED TO, PROCUREMENT OF         #
# SUBSTITUTE GOODS OR SERVICES; LOSS OF USE, DATA, OR PROFITS; OR BUSINESS     #
# INTERRUPTION) HOWEVER CAUSED AND ON ANY THEORY OF LIABILITY, WHETHER IN      #
# CONTRACT, STRICT LIABILITY, OR TORT (INCLUDING NEGLIGENCE OR OTHERWISE)      #
# ARISING IN ANY WAY OUT OF THE USE OF THIS SOFTWARE, EVEN IF ADVISED OF THE   #
# POSSIBILITY OF SUCH DAMAGE.                                                  #
################################################################################

import sys
import serial
import threading
import random
import Queue
import time
import pyaudio
import wave
import signal
import datetime
import platform
import itertools
#import serial.tools.list_ports
import glob
from PyQt4 import QtGui, QtCore
from functools import partial

from newPersonWidget import newPersonWidget


#serialPort = "/dev/ttyACM0"
serialBaud = 9600

metadataSlots = ["Metadata", "More Metadata"]


class aboutWidget(QtGui.QWidget):
    def __init__(self, parent):
        super(aboutWidget, self).__init__()
        self.setWindowTitle('About AVRFID')
        y = (parent.geometry().height()-250)/2+parent.geometry().y()
        x = (parent.geometry().width()-400)/2+parent.geometry().x()
        self.setGeometry(x, y, 400, 250)

        # create centered text
        self.inputhlayout = QtGui.QHBoxLayout()
        self.inputhlayout.addStretch(1)
        self.inputvlayout = QtGui.QVBoxLayout()
        self.inputvlayout.addStretch(1)

        # Create the domain text box
        lbl1 = QtGui.QLabel('<qt><b style="font-size:40px">AVRFID Client</b><br><i>Copyright \xa9 2012-2013 MakerPulse</i><br><br>Version 3.0 Beta<br></qt>', self)
        lbl1.setAlignment(QtCore.Qt.AlignCenter)
        self.inputvlayout.addWidget(lbl1)

        # Create the password text box
        lbl2 = QtGui.QLabel('<qt>Written by Asher Glick (aglick@aglick.com)<br/>The AVRFID client is a computer client<br>used to assist with the use of the<br>MakerPulse AVRFID RFID unit<br><a href="http://www.makerpulse.com/avrfid">Website</a></qt>', self)
        lbl2.setAlignment(QtCore.Qt.AlignCenter)
        lbl2.setOpenExternalLinks(True)
        self.inputvlayout.addWidget(lbl2)

        # Finish configuring the layput
        self.inputvlayout.addStretch(1)
        self.inputhlayout.addLayout(self.inputvlayout)
        self.inputhlayout.addStretch(1)
        # Set the layout to the hlayout
        self.setLayout(self.inputhlayout)
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

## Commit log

2012-05-31 First RCOS commit - RFID reader board and schematic with RFID chip, microcontroller, real time clock, USB LiPO charger, and boost converter.
    [rfid1.brd, rfid1.sch]
2012-06-08 Updated part sizes and added acces pads for unused avr pins. Added silk labels and free area. Revision sent for manufacturing 6/4/12
    [rfid1.brd, rfid1.sch]
2012-06-23 Cad files for a case holding reader, battery, leds
    [Assem1.SLDASM, PCB.SLDPRT, battery.SLDPRT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]
2012-07-14 removed compile errors, now to begin to port the pinmappings over to arduino
    [RPI_RFID.ino]
2012-07-14 split up the main function into the two arduino functions
2012-07-14 fixed a couple of declaration bugs
    [RPI_RFID.ino]
2012-07-14 removed the last whitelist line and removed some servo init lines
2012-07-14 realized that the avrfid only uses the timers for the servos, got rid of them
2012-07-14 tried to switch the interrupts to arduino, did not work
    [RPI_RFID.ino]
2012-07-15 getting the interrupts to work is hard
2012-07-15 got the interrupts to work, slight problems with some serial ports going missing though
    [RPI_RFID.ino]
2012-07-15 I was reading from the wrong pin, pin 2 is actualy 0x04 not 0x02
    [RPI_RFID.ino]
2012-07-18 swapped out the actual array type for a defined type
    [RPI_RFID.ino]
2012-07-19 One number, one tiny little ittybity mini number. 9 hours of work wasted because it was wrong. Two people did not find it either.
    [RPI_RFID.ino]
2012-07-19 board can read cards, still needs some tweaking to solve some read errors, and a glitch where the serial port freezes
    [RPI_RFID.ino]
2012-07-29 removed the debug print statements, ids scan much faster now
2012-09-21 created gui application in processing. Doesnt save or read rfids yet. opens file, lists names, adds names, opens serial port, search works
    [Assem1.SLDASM, side1.SLDPRT, side1.STL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]
2012-09-23 added mark button and present attribute
2012-09-24 highlighted current entry, bug fixes and tweaks, see instructions
2012-10-20 made the output just display hex, and made an led blink when a card is read
2012-10-20 fixed a problem with the delay function not working because all interrupts were disabled
    [RPI_RFID.ino]
2012-11-26 created a basic program to begin reading tags using samplecode
2012-11-27 changed the read to a non-blocking read so that the child thread will quit when the parent does
2012-11-29 UI now correctly reads tags
    [pythonRFIDInterface.py]
2012-11-29 added a new button for connecting the RFID reader
2012-11-29 started creating the buttons for interacting with the program
2012-12-01 added new buttons that do not do anything yet
2012-12-01 fixed the partial tag read function
    [pythonRFIDInterface.py]
2012-12-01 adding buttons to the add user box
2012-12-01 added a warning message to prevent the close button from accadentaly being hit
    [pythonRFIDInterface.py]
2012-12-03 made the search case insensitive
2012-12-13 added support for detecting when a divice is plugged into the computer, beginning to use it to auto detect arduinos
2012-12-13 program now automaticly spawns a new thread for each new divice attached to the computer
2012-12-17 addded error catching to try to debug the program on windows
    [pythonRFIDInterface.py]
2012-12-17 added a line to detect if the threading library is breaking
2012-12-17 removed the debug line to prevent it from clashing with threads debug messages
    [pythonRFIDInterface.py]
2012-12-17 removed the threads to see what the serial library is doing on windows
2012-12-17 debug messaging to print all of the ports attached
2012-12-17 added a length of the current ports to be displayed durring the function
2013-01-22 removed the connect rfid reader button as the reader will connect automaticly
2013-01-22 updating the interface buttons to save and load the attendance sheets
2013-04-05 disabled serial during the reading from the antenna interrrupt
2013-04-07 fixed a frezing error caused by an out of bounds error
    [RPI_RFID.ino]
2013-04-07 removed the extra serial print functions, added printout for id tag
2013-04-07 Moved the circuit board schematics into their own folder
    [rfid1.brd, rfid1.sch]
2013-04-07 renamed the cad folder to CaseCad
    [Assem1.SLDASM, PCB.SLDPRT, battery.SLDPRT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]
2013-04-08 fixed probelm with passing wrong view into new user widget
    [pythonRFIDInterface.py]
2013-04-09 changed notifaction noise code to play in a thread instead of blocking
    [pythonRFIDInterface.py]
2013-04-11 reversed the order of the attendance list so new tags apear on the top of the list
    [pythonRFIDInterface.py]
2013-04-22 added an array to define what kind of metadata should be present in the new user field fixes #5
    [pythonRFIDInterface.py]
2013-04-22 fixed a bug where program crashes if the database is not present
    [pythonRFIDInterface.py]
2013-06-26 fixed error wiht calling IDRelation before initilizing it
    [pythonRFIDInterface.py]
2013-06-26 updated edit ability to allow for editing from the currently scanned tags
2013-06-27 added menu options for all currently planned features
2013-06-27 added the ctrl+c interrupt to kill the program
2013-06-27 added a second message passing interface to the threaded tasks
2013-06-28 finished error catching for the time being
    [pythonRFIDInterface.py]
2013-06-28 created a list of currently open serial ports to be used with the menu
2013-06-28 currently active serial ports are displayed on the connection menu
2013-07-01 fixed a few dumb pyadio mistakes
    [pythonRFIDInterface.py]
2013-07-01 fixed a forgotten stream close
    [pythonRFIDInterface.py]
2013-07-01 fixed a quit bug
    [pythonRFIDInterface.py]
2013-07-01 fixed a mistake from a refactor
    [pythonRFIDInterface.py]

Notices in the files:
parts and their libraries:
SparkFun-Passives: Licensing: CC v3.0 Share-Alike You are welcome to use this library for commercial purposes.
